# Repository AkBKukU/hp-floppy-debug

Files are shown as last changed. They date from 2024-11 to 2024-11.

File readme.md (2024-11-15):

# Floppy Poser

**UNTESTED DESIGN**
*This board has not been produced and ordered yet. The software to drive it doesn't even exist at this time. DO NOT BUILD THIS!*

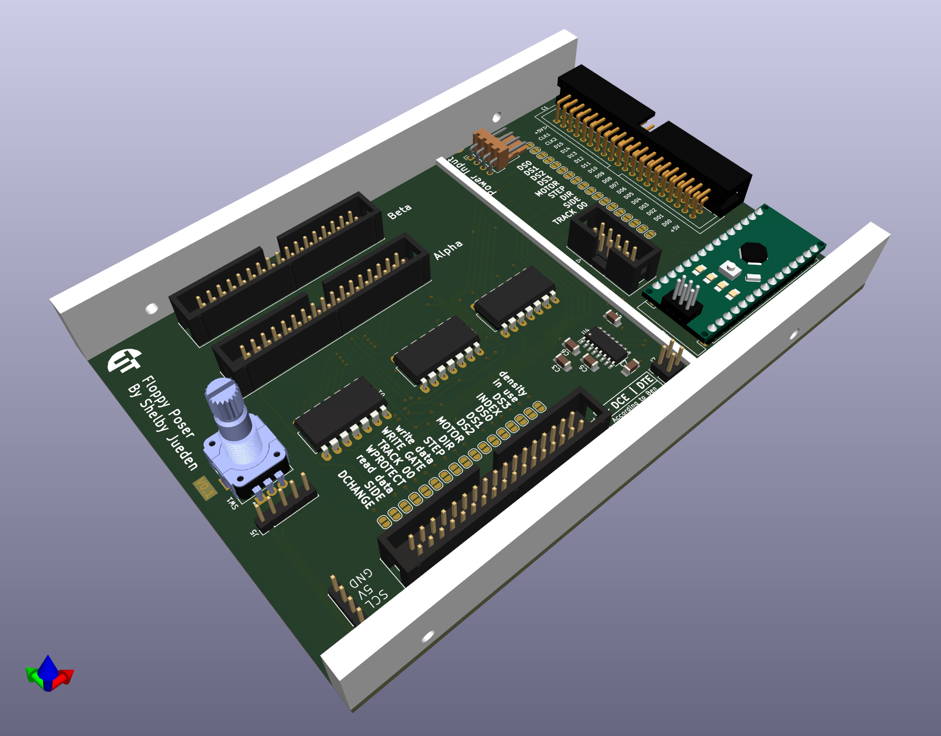
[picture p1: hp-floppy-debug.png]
A rendering of the board A rendering of the circuit board


## What this technically is

This is a ground up redo of my [Floppy Switch Board](https://github.com/AkBKukU/FloppySwitchBoard) that is controlled by an Arduino instead of a switch. Additionally, it uses buffer chips to switch more than before and can switch between two different drive pairs entirely.

## What this really is

I'm working towards a larger project and needed a test bed for a few concepts and the amility to probe a floppy bus with an HP probe pod directly. So this has some more features related to that which are useless for anyone else.

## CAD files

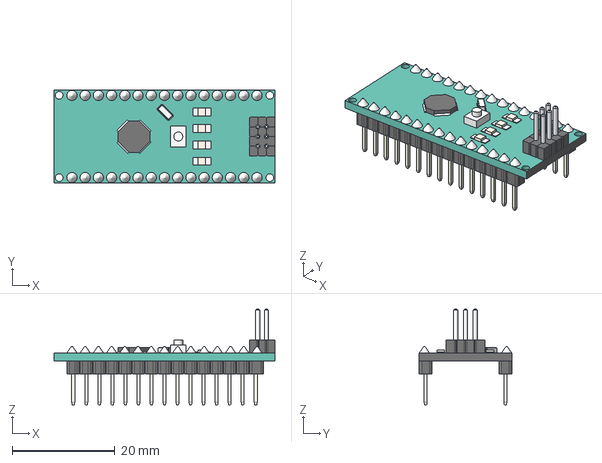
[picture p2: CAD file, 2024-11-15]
models/Arduino v5.step
43.0 x 18.0 x 18.6 mm

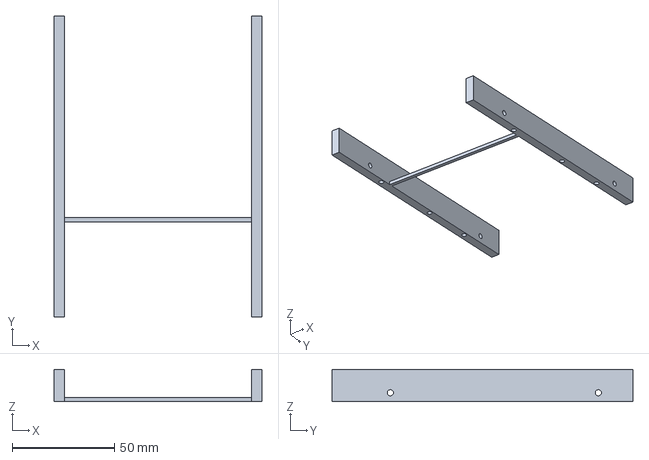
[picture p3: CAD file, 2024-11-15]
models/35in-PCB-mount.3mf
101.6 x 147.0 x 15.8 mm

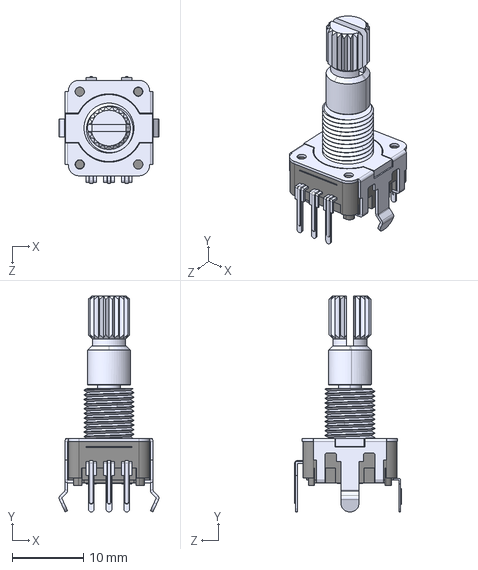
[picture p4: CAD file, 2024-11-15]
models/PEC11R-4220K-S0024.STEP
14.0 x 30.3 x 14.9 mm

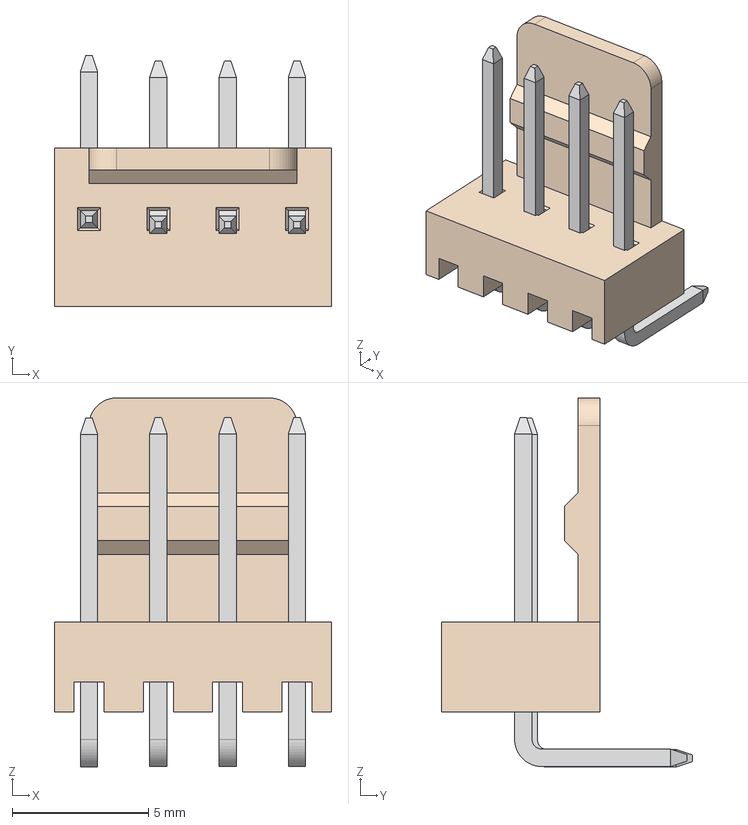
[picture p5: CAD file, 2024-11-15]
models/61900411021.step
10.2 x 9.20 x 13.5 mm
6190xx1xx21_PIN x 4

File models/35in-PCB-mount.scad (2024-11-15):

$fn=48;

// WD HDD Dimmensions
// https://support.wdc.com/images/kb/2579-771970-A03.pdf
// Alt mount : https://pro.sony/s3/cms-static-content/operation-manual/4668278111.pdf
A1=17.8; // Height Min
A2=147;  // Length Max
A3=101.6;// Width

// Bottom Side
A5=3.18; // Bottom Screw Inset
A7=41.28;// First Mount
A6=44.45;// Second Mount Offset from first
A13=76.2;// Third Mount Offset from first

// Walls
A10=6.35; // Screw rise
A8=28.50; // First Mount
A9=101.60; // Second Mount

pcb_thickness=1.5875; // 1/16th of an in

brace_thick=2;
brace_spacing=48.5-brace_thick/2;

difference()
{
    union()
    {
difference(){
        union()
        {
            cube([5.175,A2,A1]);
            translate([A3-5.175,0,0])cube([5.175,A2,A1]);
            translate([0,brace_spacing,pcb_thickness])cube([A3,brace_thick,brace_thick]);
        }
        cube([A3,A2,2]);}
    }

translate([A5,A7,-1])cylinder(8,1.5,1.5);
translate([A3-A5,A7,-1])cylinder(8,1.5,1.5);
    
translate([A5,A7+A6,-1])cylinder(8,1.5,1.5);
translate([A3-A5,A7+A6,-1])cylinder(8,1.5,1.5);
    
translate([A5,A7+A13,-1])cylinder(8,1.5,1.5);
translate([A3-A5,A7+A13,-1])cylinder(8,1.5,1.5);
    
    
translate([-1,A8,A10])rotate([0,90,0])cylinder(800,1.5,1.5);
translate([-1,A8+A9,A10])rotate([0,90,0])cylinder(800,1.5,1.5);
}

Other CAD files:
models/35in-PCB-mount.stl

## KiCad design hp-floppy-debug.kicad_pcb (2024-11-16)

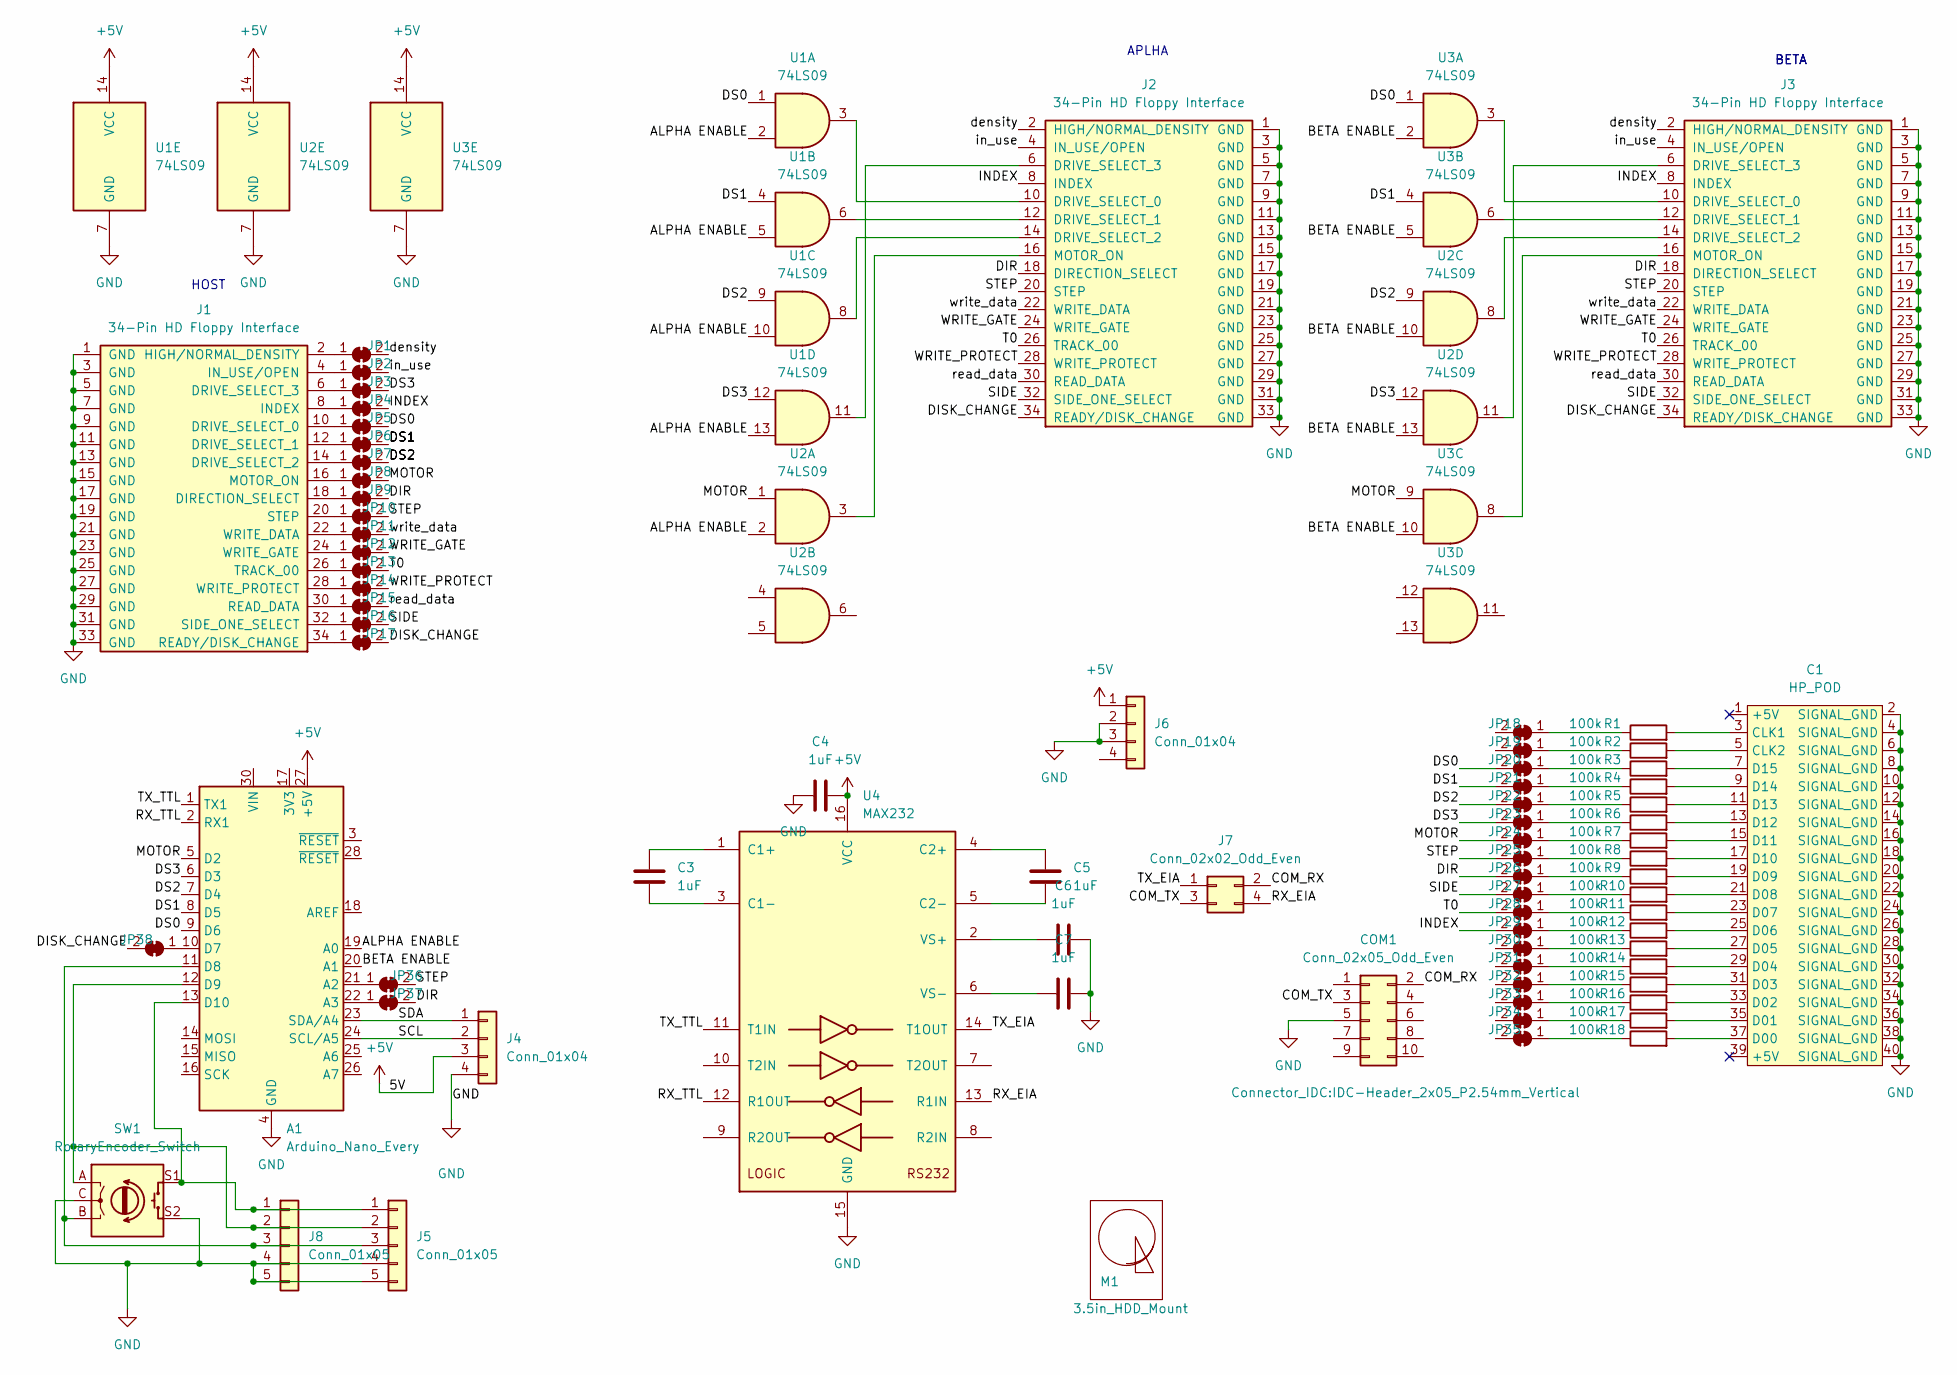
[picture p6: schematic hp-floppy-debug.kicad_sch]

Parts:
A1: Arduino_Nano_Every; Arduino_Nano
C1: HP_POD; HP Probe POD; Manufacturer Part Number 302-S401
C3, C4, C5, C6, C7: 1uF; C_1206_3216Metric_Pad1.33x1.80mm_HandSolder; Manufacturer Part Number GMC31X7R105M100NT
COM1: Conn_02x05_Odd_Even; IDC-Header_2x05_P2.54mm_Vertical; Manufacturer Part Number CH87102V200
J1, J2, J3: 34-Pin HD Floppy Interface; IDC-Header_2x17_P2.54mm_Vertical; Manufacturer Part Number 302-S341
J4: Conn_01x04; PinHeader_1x04_P2.54mm_Vertical
J5, J8: Conn_01x05; PinHeader_1x05_P2.54mm_Vertical
J6: Conn_01x04; PinHeader_1x04_P2.54mm_Horizontal; Manufacturer Part Number 171826-4
J7: Conn_02x02_Odd_Even; PinHeader_2x02_P2.54mm_Vertical
JP1, JP2, JP3, JP4, JP5, JP6, JP7, JP8, JP9, JP10, JP11, JP12, JP13, JP14, JP15, JP16, JP17, JP18, JP19, JP20, JP21, JP22, JP23, JP24, JP25, JP26, JP27, JP28, JP29, JP30, JP31, JP32, JP33, JP34, JP35, JP36, JP37, JP38: SolderJumper_2_Bridged; SolderJumper-2_P1.3mm_Bridged_RoundedPad1.0x1.5mm
M1: 3.5in_HDD_Mount; 3.5in HDD Bottom Mount
R1, R2, R3, R4, R5, R6, R7, R8, R9, R10, R11, R12, R13, R14, R15, R16, R17, R18: 100k; R_0603_1608Metric_Pad0.98x0.95mm_HandSolder; Manufacturer Part Number RC0603FR-7W100KL
SW1: RotaryEncoder_Switch; RotaryEncoder_Alps_EC11E-Switch_Vertical_H20mm; Manufacturer Part Number PEC11R-4220K-S0024
U1, U2, U3: 74LS09; DIP-14_W10.16mm_LongPads; Manufacturer Part Number SN74LS09N
U4: MAX232; SOIC-16_3.9x9.9mm_P1.27mm; Manufacturer Part Number MAX232DR

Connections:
+5V: A1.27 (+5V), C4.1, J4.3, J6.1, U1.14 (VCC), U2.14 (VCC), U3.14 (VCC), U4.16 (VCC)
/ALPHA ENABLE: A1.19 (A0), U1.2, U1.5, U1.10, U1.13, U2.2
/BETA ENABLE: A1.20 (A1), U2.10, U2.13, U3.2, U3.5, U3.10
/COM_RX: COM1.2, J7.2
/COM_TX: COM1.3, J7.3
/DIR: J2.18 (DIRECTION_SELECT), J3.18 (DIRECTION_SELECT), JP9.2 (B), JP26.2 (B), JP37.2 (B)
/DISK_CHANGE: J2.34 (READY/DISK_CHANGE), J3.34 (READY/DISK_CHANGE), JP17.2 (B), JP38.2 (B)
/DS0: A1.9 (D6), JP5.2 (B), JP20.2 (B), U1.1, U3.1
/DS1: A1.8 (D5), JP6.2 (B), JP21.2 (B), U1.4, U3.4
/DS2: A1.7 (D4), JP7.2 (B), JP22.2 (B), U1.9, U2.9
/DS3: A1.6 (D3), JP3.2 (B), JP23.2 (B), U1.12, U2.12
/INDEX: J2.8 (INDEX), J3.8 (INDEX), JP4.2 (B), JP29.2 (B)
/MOTOR: A1.5 (D2), JP8.2 (B), JP24.2 (B), U2.1, U3.9
/RX_EIA: J7.4, U4.13 (R1IN)
/RX_TTL: A1.2 (RX1), U4.12 (R1OUT)
/SCL: A1.24 (SCL/A5), J4.2
/SDA: A1.23 (SDA/A4), J4.1
/SIDE: J2.32 (SIDE_ONE_SELECT), J3.32 (SIDE_ONE_SELECT), JP16.2 (B), JP27.2 (B)
/STEP: J2.20 (STEP), J3.20 (STEP), JP10.2 (B), JP25.2 (B), JP36.2 (B)
/T0: J2.26 (TRACK_00), J3.26 (TRACK_00), JP13.2 (B), JP28.2 (B)
/TX_EIA: J7.1, U4.14 (T1OUT)
/TX_TTL: A1.1 (TX1), U4.11 (T1IN)
/WRITE_GATE: J2.24 (WRITE_GATE), J3.24 (WRITE_GATE), JP12.2 (B)
/WRITE_PROTECT: J2.28 (WRITE_PROTECT), J3.28 (WRITE_PROTECT), JP14.2 (B)
/density: J2.2 (HIGH/NORMAL_DENSITY), J3.2 (HIGH/NORMAL_DENSITY), JP1.2 (B)
/in_use: J2.4 (IN_USE/OPEN), J3.4 (IN_USE/OPEN), JP2.2 (B)
/read_data: J2.30 (READ_DATA), J3.30 (READ_DATA), JP15.2 (B)
/write_data: J2.22 (WRITE_DATA), J3.22 (WRITE_DATA), JP11.2 (B)
GND: A1.4 (GND), A1.29 (GND), C1.2 (SIGNAL_GND), C1.4 (SIGNAL_GND), C1.6 (SIGNAL_GND), C1.8 (SIGNAL_GND), C1.10 (SIGNAL_GND), C1.12 (SIGNAL_GND), C1.14 (SIGNAL_GND), C1.16 (SIGNAL_GND), C1.18 (SIGNAL_GND), C1.20 (SIGNAL_GND), C1.22 (SIGNAL_GND), C1.24 (SIGNAL_GND), C1.26 (SIGNAL_GND), C1.28 (SIGNAL_GND), C1.30 (SIGNAL_GND), C1.32 (SIGNAL_GND), C1.34 (SIGNAL_GND), C1.36 (SIGNAL_GND), C1.38 (SIGNAL_GND), C1.40 (SIGNAL_GND), C4.2, C6.2, C7.2, COM1.5, J1.1 (GND), J1.3 (GND), J1.5 (GND), J1.7 (GND), J1.9 (GND), J1.11 (GND), J1.13 (GND), J1.15 (GND), J1.17 (GND), J1.19 (GND), J1.21 (GND), J1.23 (GND), J1.25 (GND), J1.27 (GND), J1.29 (GND), J1.31 (GND), J1.33 (GND), J2.1 (GND), J2.3 (GND), J2.5 (GND), J2.7 (GND), J2.9 (GND), J2.11 (GND), J2.13 (GND), J2.15 (GND), J2.17 (GND), J2.19 (GND), J2.21 (GND), J2.23 (GND), J2.25 (GND), J2.27 (GND), J2.29 (GND), J2.31 (GND), J2.33 (GND), J3.1 (GND), J3.3 (GND), J3.5 (GND), J3.7 (GND), J3.9 (GND), J3.11 (GND), J3.13 (GND), J3.15 (GND), J3.17 (GND), J3.19 (GND), J3.21 (GND), J3.23 (GND), J3.25 (GND), J3.27 (GND), J3.29 (GND), J3.31 (GND), J3.33 (GND), J4.4, J5.4, J5.5, J6.2, J6.3, J8.4, J8.5, SW1.C, SW1.S2, U1.7 (GND), U2.7 (GND), U3.7 (GND), U4.15 (GND)
unnamed: A1.10 (D7), JP38.1 (A)
unnamed: A1.11 (D8), J5.3, J8.3, SW1.B
unnamed: A1.12 (D9), J5.2, J8.2, SW1.A
unnamed: A1.13 (D10), J5.1, J8.1, SW1.S1
unnamed: A1.21 (A2), JP36.1 (A)
unnamed: A1.22 (A3), JP37.1 (A)
unnamed: C1.3 (CLK1), R1.2
unnamed: C1.5 (CLK2), R2.2
unnamed: C1.7 (D15), R3.2
unnamed: C1.9 (D14), R4.2
unnamed: C1.11 (D13), R5.2
unnamed: C1.13 (D12), R6.2
unnamed: C1.15 (D11), R7.2
unnamed: C1.17 (D10), R8.2
unnamed: C1.19 (D09), R9.2
unnamed: C1.21 (D08), R10.2
unnamed: C1.23 (D07), R11.2
unnamed: C1.25 (D06), R12.2
unnamed: C1.27 (D05), R13.2
unnamed: C1.29 (D04), R14.2
unnamed: C1.31 (D03), R15.2
unnamed: C1.33 (D02), R16.2
unnamed: C1.35 (D01), R17.2
unnamed: C1.37 (D00), R18.2
unnamed: C3.1, U4.1 (C1+)
unnamed: C3.2, U4.3 (C1-)
unnamed: C5.1, U4.4 (C2+)
unnamed: C5.2, U4.5 (C2-)
unnamed: C6.1, U4.2 (VS+)
unnamed: C7.1, U4.6 (VS-)
unnamed: J1.2 (HIGH/NORMAL_DENSITY), JP1.1 (A)
unnamed: J1.4 (IN_USE/OPEN), JP2.1 (A)
unnamed: J1.6 (DRIVE_SELECT_3), JP3.1 (A)
unnamed: J1.8 (INDEX), JP4.1 (A)
unnamed: J1.10 (DRIVE_SELECT_0), JP5.1 (A)
unnamed: J1.12 (DRIVE_SELECT_1), JP6.1 (A)
unnamed: J1.14 (DRIVE_SELECT_2), JP7.1 (A)
unnamed: J1.16 (MOTOR_ON), JP8.1 (A)
unnamed: J1.18 (DIRECTION_SELECT), JP9.1 (A)
unnamed: J1.20 (STEP), JP10.1 (A)
unnamed: J1.22 (WRITE_DATA), JP11.1 (A)
unnamed: J1.24 (WRITE_GATE), JP12.1 (A)
unnamed: J1.26 (TRACK_00), JP13.1 (A)
unnamed: J1.28 (WRITE_PROTECT), JP14.1 (A)
unnamed: J1.30 (READ_DATA), JP15.1 (A)
unnamed: J1.32 (SIDE_ONE_SELECT), JP16.1 (A)
unnamed: J1.34 (READY/DISK_CHANGE), JP17.1 (A)
unnamed: J2.6 (DRIVE_SELECT_3), U1.11
unnamed: J2.10 (DRIVE_SELECT_0), U1.3
unnamed: J2.12 (DRIVE_SELECT_1), U1.6
unnamed: J2.14 (DRIVE_SELECT_2), U1.8
unnamed: J2.16 (MOTOR_ON), U2.3
unnamed: J3.6 (DRIVE_SELECT_3), U2.11
unnamed: J3.10 (DRIVE_SELECT_0), U3.3
unnamed: J3.12 (DRIVE_SELECT_1), U3.6
unnamed: J3.14 (DRIVE_SELECT_2), U2.8
unnamed: J3.16 (MOTOR_ON), U3.8
unnamed: JP18.1 (A), R1.1
unnamed: JP19.1 (A), R2.1
unnamed: JP20.1 (A), R3.1
unnamed: JP21.1 (A), R4.1
unnamed: JP22.1 (A), R5.1
unnamed: JP23.1 (A), R6.1
unnamed: JP24.1 (A), R7.1
unnamed: JP25.1 (A), R8.1
unnamed: JP26.1 (A), R9.1
unnamed: JP27.1 (A), R10.1
unnamed: JP28.1 (A), R11.1
unnamed: JP29.1 (A), R12.1
unnamed: JP30.1 (A), R13.1
unnamed: JP31.1 (A), R14.1
unnamed: JP32.1 (A), R15.1
unnamed: JP33.1 (A), R16.1
unnamed: JP34.1 (A), R17.1
unnamed: JP35.1 (A), R18.1

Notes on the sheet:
HOST
BETA
APLHA

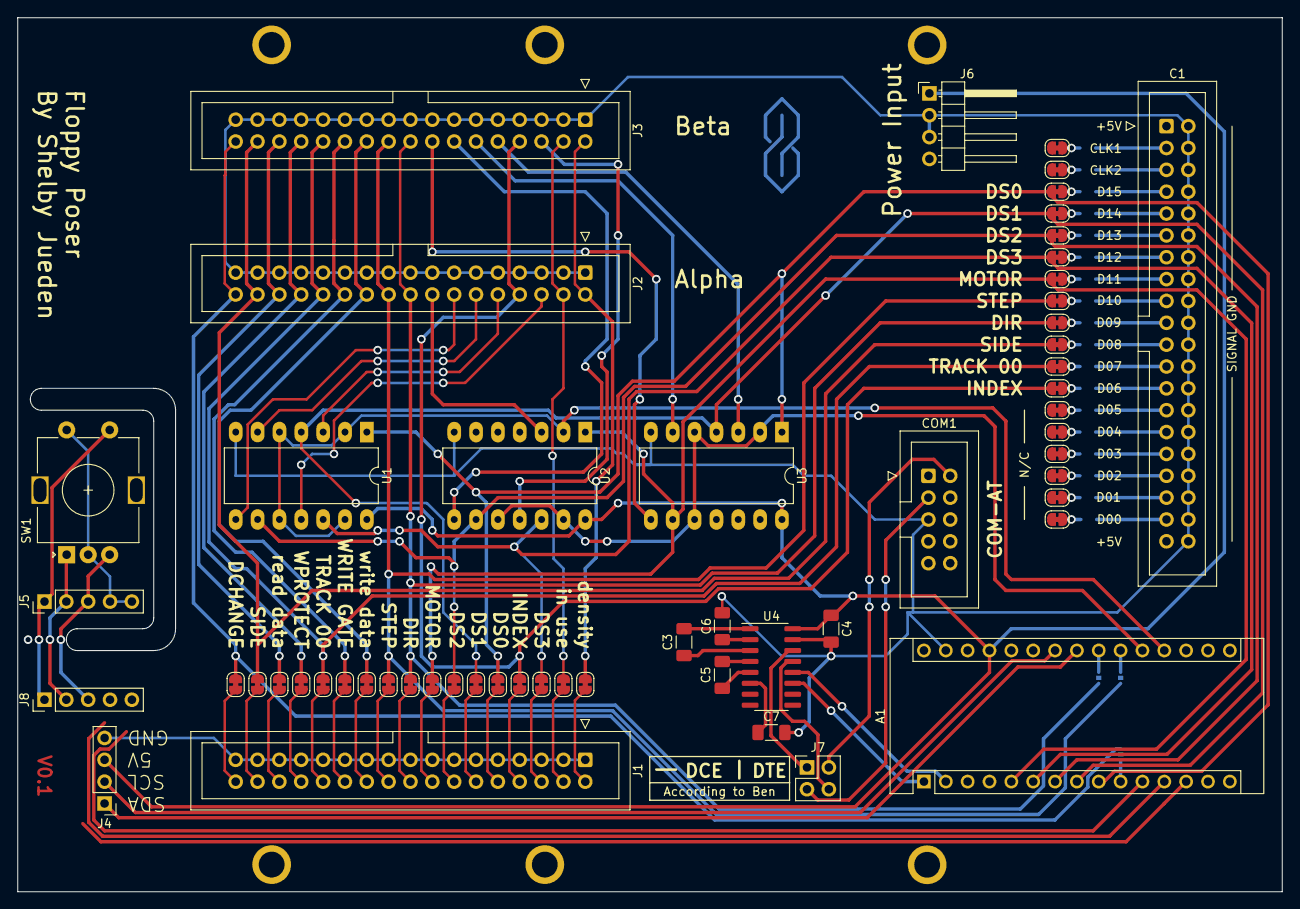
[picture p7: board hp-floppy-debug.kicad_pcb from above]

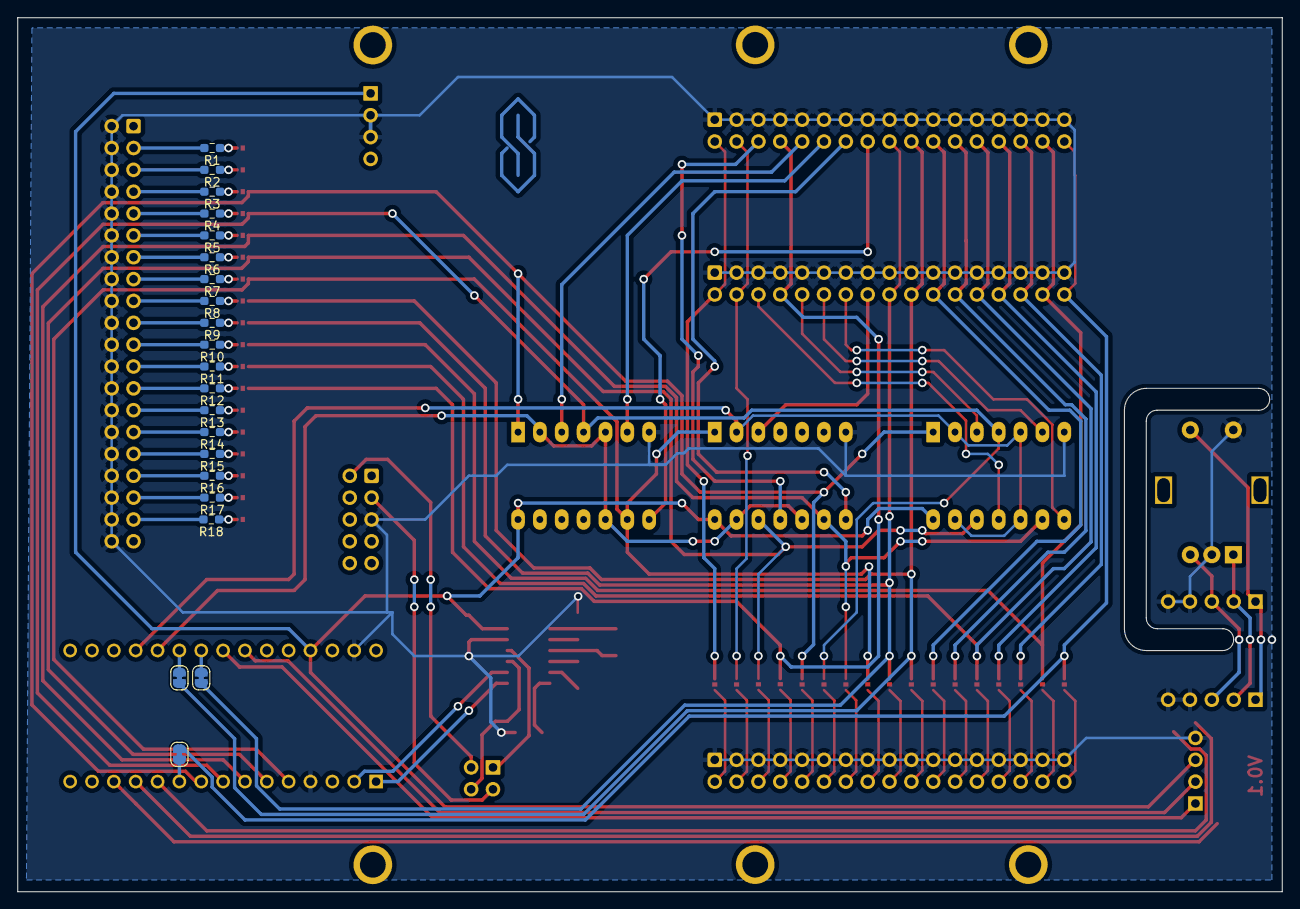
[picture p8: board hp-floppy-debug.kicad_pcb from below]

Board: 2 copper layers, 147.0 x 101.6 mm, 78 parts (21 on the bottom side), 104 nets.

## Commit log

2024-11-15 review changes
    [35in-PCB-mount.scad, hp-floppy-debug.kicad_pcb, hp-floppy-debug.kicad_sch]
2024-11-16 Remove unconnected trace
    [hp-floppy-debug.kicad_pcb]
